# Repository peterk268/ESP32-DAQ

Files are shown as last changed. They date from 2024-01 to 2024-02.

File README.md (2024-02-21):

# V2

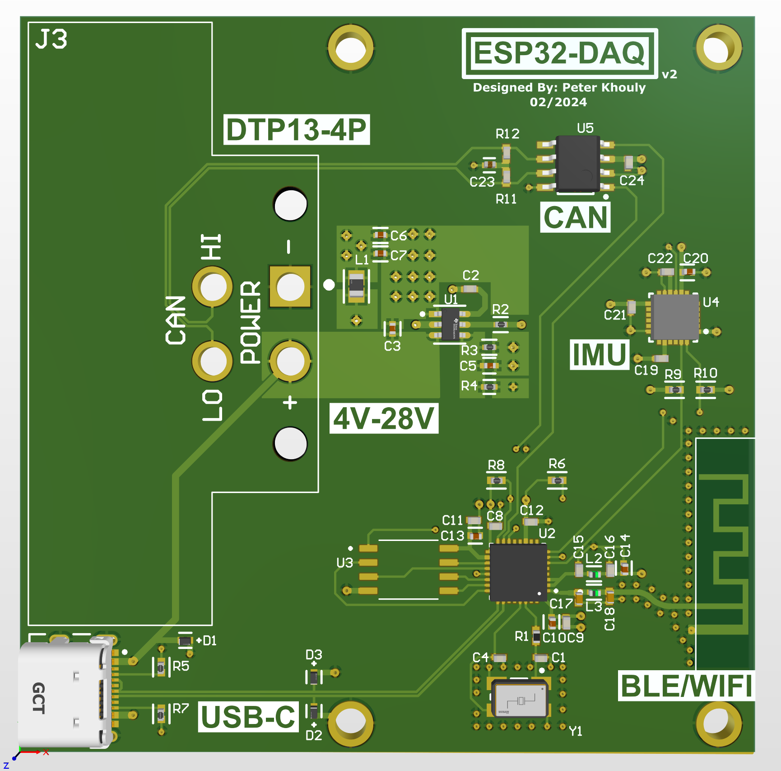
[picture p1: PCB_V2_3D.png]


# V1

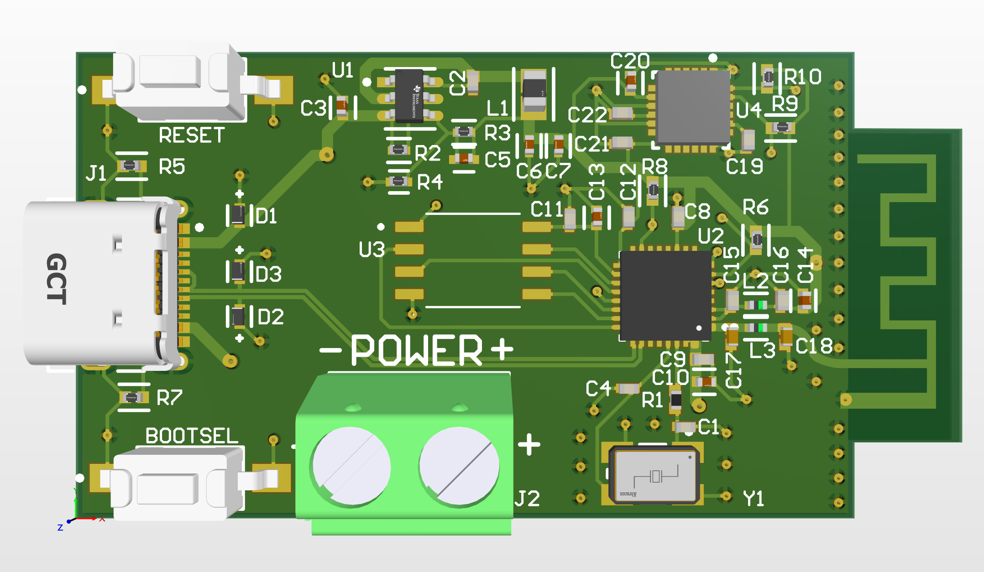
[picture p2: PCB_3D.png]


[Schematic.pdf](https://github.com/peterk268/ESP32-DAQ/blob/main/Schematic.pdf)

[PCB.pdf](https://github.com/peterk268/ESP32-DAQ/blob/main/PCB.pdf)

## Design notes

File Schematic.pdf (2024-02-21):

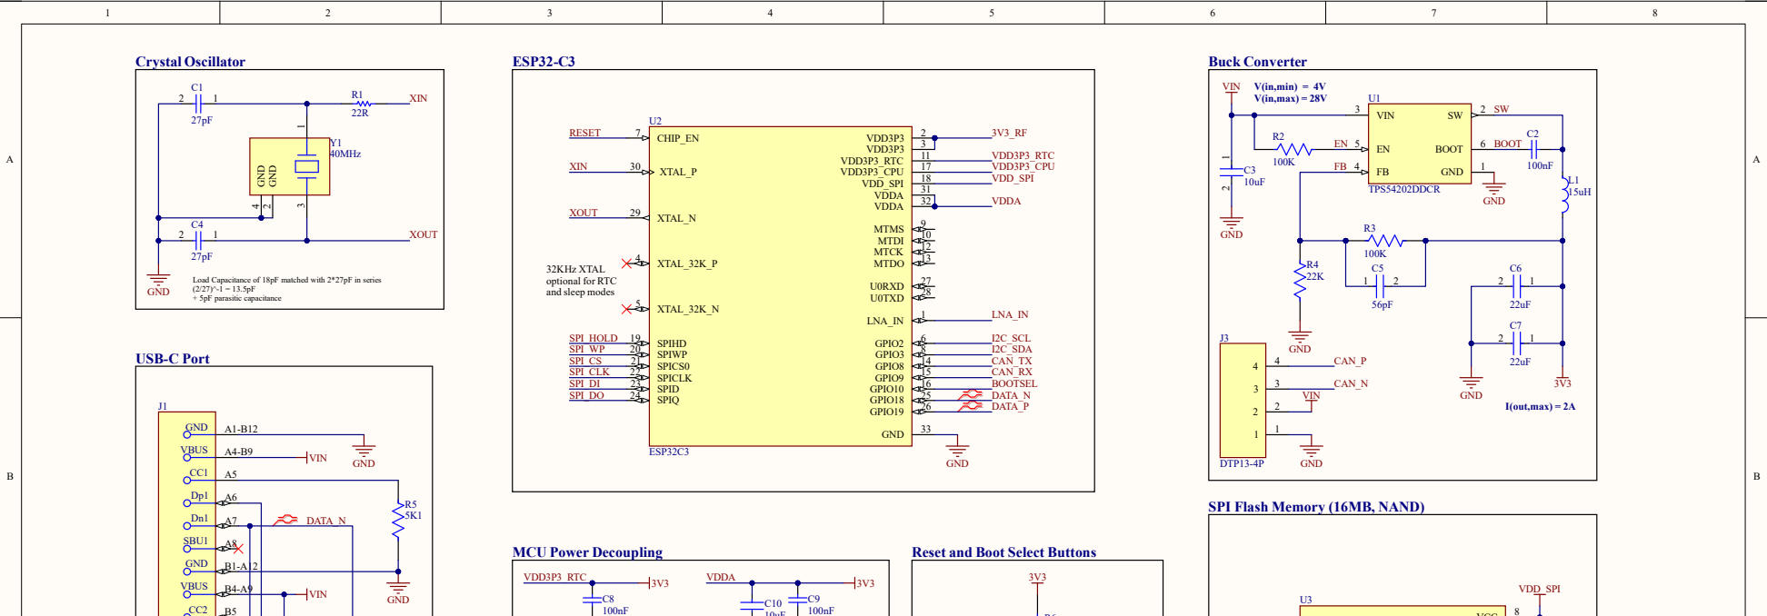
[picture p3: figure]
DATA_N; USB-C Port; VIN; GND; VBUS; SBU1; Crystal Oscillator; XIN; XOUT; (2/27)^-1 = 13.5pF + 5pF parasitic capacitance; Buck Converter 1 2; VIN 3; BOOT; TPS54202DDCR; V(in,max) = 28V; I(out,max) = 2A; CHIP_EN 7; XTAL_P 30; XTAL_N 29; XTAL_32K_P 4; XTAL_32K_N 5; SPIHD 19 SPIWP 20 SPICS0 21 SPICLK 22 SPID 23 SPIQ 24; VDD3P3; VDD3P3_RTC; VDD3P3_CPU; VDD_SPI; VDDA; MTMS; MTDI; MTCK; MTDO; U0RXD; U0TXD; LNA_IN; GPIO2; GPIO3; GPIO8; GPIO9; GPIO10; GPIO18; GPIO19; ESP32C3; DATA_N DATA_P; 32KHz XTAL optional for RTC and sleep modes; VDD3P3_RTC VDD3P3_CPU VDD_SPI; 1 GND; 3 GND; Y1 40MHz; RESET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
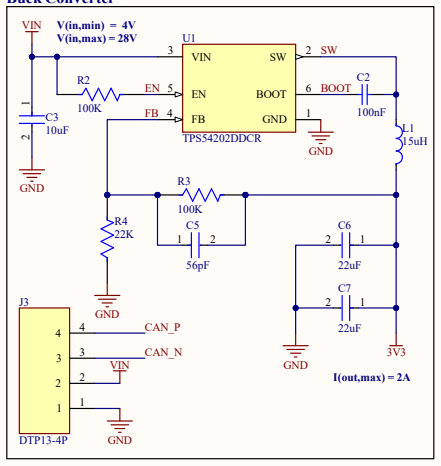
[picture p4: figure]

Load Capacitance of 18pF matched with 2*27pF in series

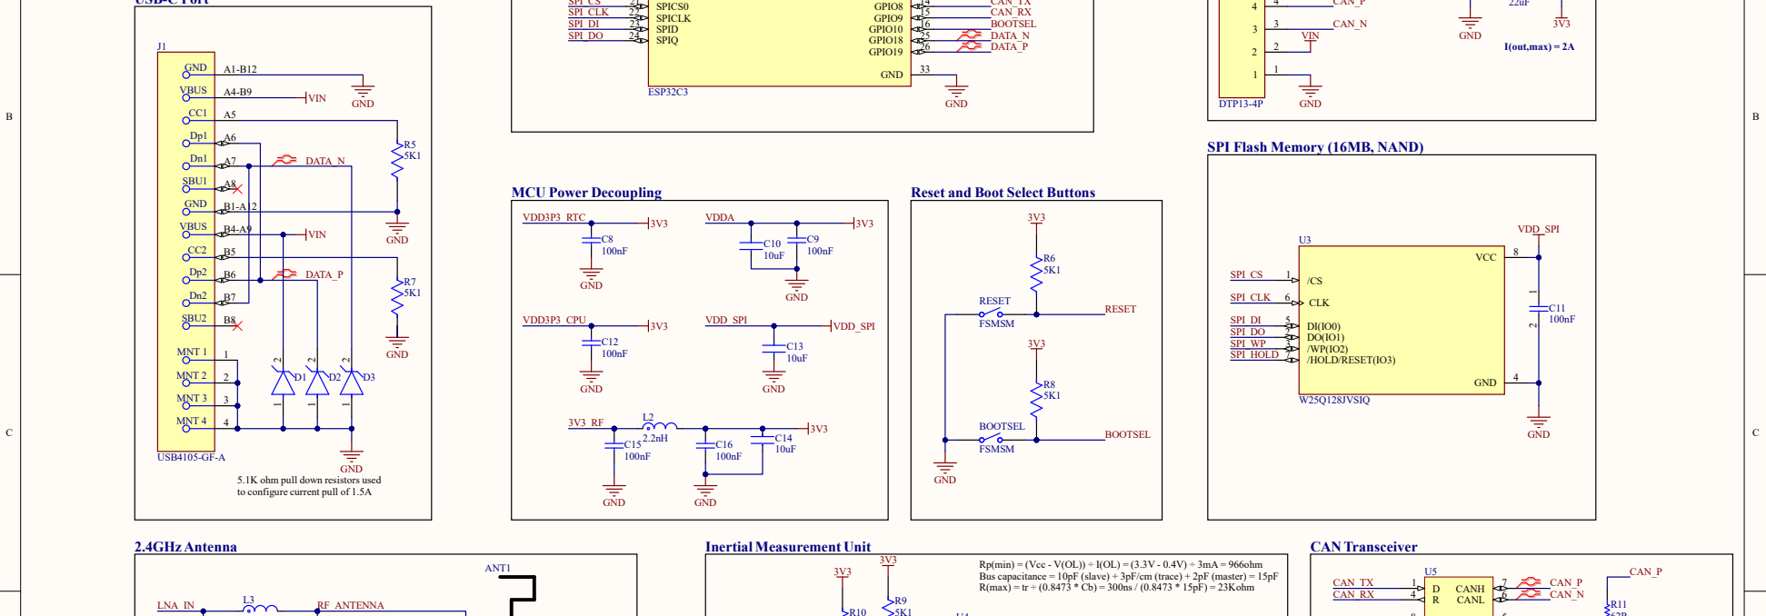
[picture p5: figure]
GND; DATA_P; MNT 1; MNT 2; MNT 3; MNT 4; SBU2; USB4105-GF-A; 5.1K ohm pull down resistors used to configure current pull of 1.5A; GND ¹ ²; VDD3P3_CPU; VDD_SPI; RESET; FSMSM; BOOTSEL; CLK 6; DI(IO0) 5 DO(IO1) 2 /WP(IO2) 3 /HOLD/RESET(IO3) 7; VCC; W25Q128JVSIQ; SPI_CS; SPI_CLK; SPI_DI SPI_DO SPI_WP; SPI_HOLD; 2.4GHz Antenna; ANT1; Inertial Measurement Unit; CANL; CANH; CAN_TX CAN_RX; CAN_P CAN_N; CAN_P; CAN Transceiver
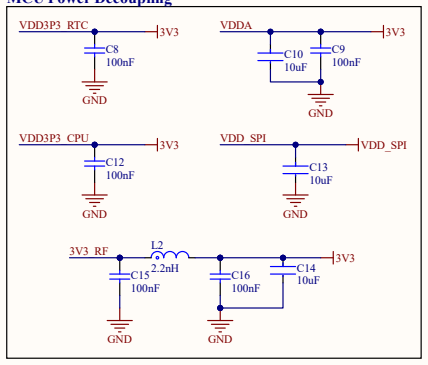
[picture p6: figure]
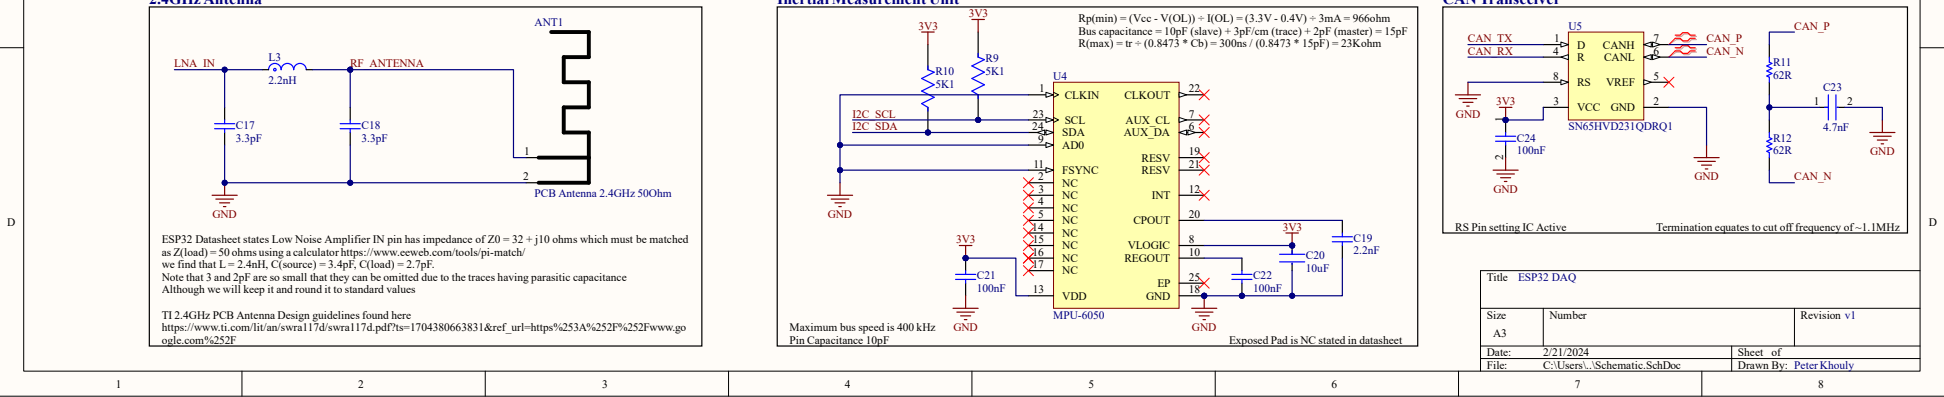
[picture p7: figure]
Title; Size; Number; Revision; Date:; Sheet of; File:; C:\Users\..\Schematic.SchDoc; Drawn By:; https://www.ti.com/lit/an/swra117d/swra117d.pdf?ts=1704380663831&ref_url=https%253A%252F%252Fwww.go ogle.com%252F; LNA_IN; RF_ANTENNA; GND; PCB Antenna 2.4GHz 50Ohm; ESP32 DAQ; Peter Khouly; CLKIN 1; AUX_DA; AUX_CL; VLOGIC; REGOUT; FSYNC 11; INT; VDD 13; RESV; CPOUT; CLKOUT; SCL 23 SDA 24; MPU-6050; Maximum bus speed is 400 kHz Pin Capacitance 10pF; I2C_SCL I2C_SDA; Exposed Pad is NC stated in datasheet; 2 VCC 3; VREF; SN65HVD231QDRQ1; GND ¹ ² C24 100nF; CAN_N

ESP32 Datasheet states Low Noise Amplifier IN pin has impedance of Z0 = 32 + j10 ohms which must be matched as Z(load) = 50 ohms using a calculator https://www.eeweb.com/tools/pi-match/
we find that L = 2.4nH, C(source) = 3.4pF, C(load) = 2.7pF.
Note that 3 and 2pF are so small that they can be omitted due to the traces having parasitic capacitance
Although we will keep it and round it to standard values

TI 2.4GHz PCB Antenna Design guidelines found here

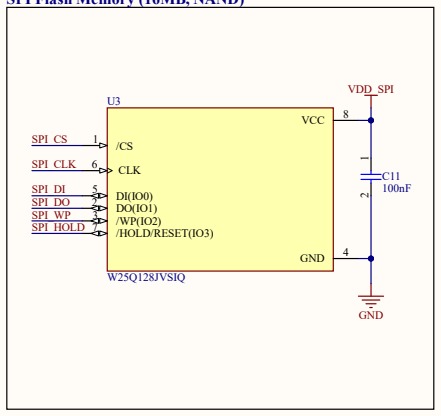
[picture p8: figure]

Rp(min) = (Vcc - V(OL)) ÷ I(OL) = (3.3V - 0.4V) ÷ 3mA = 966ohm Bus capacitance = 10pF (slave) + 3pF/cm (trace) + 2pF (master) = 15pF R(max) = tr ÷ (0.8473 * Cb) = 300ns / (0.8473 * 15pF) = 23Kohm

RS Pin setting IC Active | Termination equates to cut off frequency of ~1.1MHz

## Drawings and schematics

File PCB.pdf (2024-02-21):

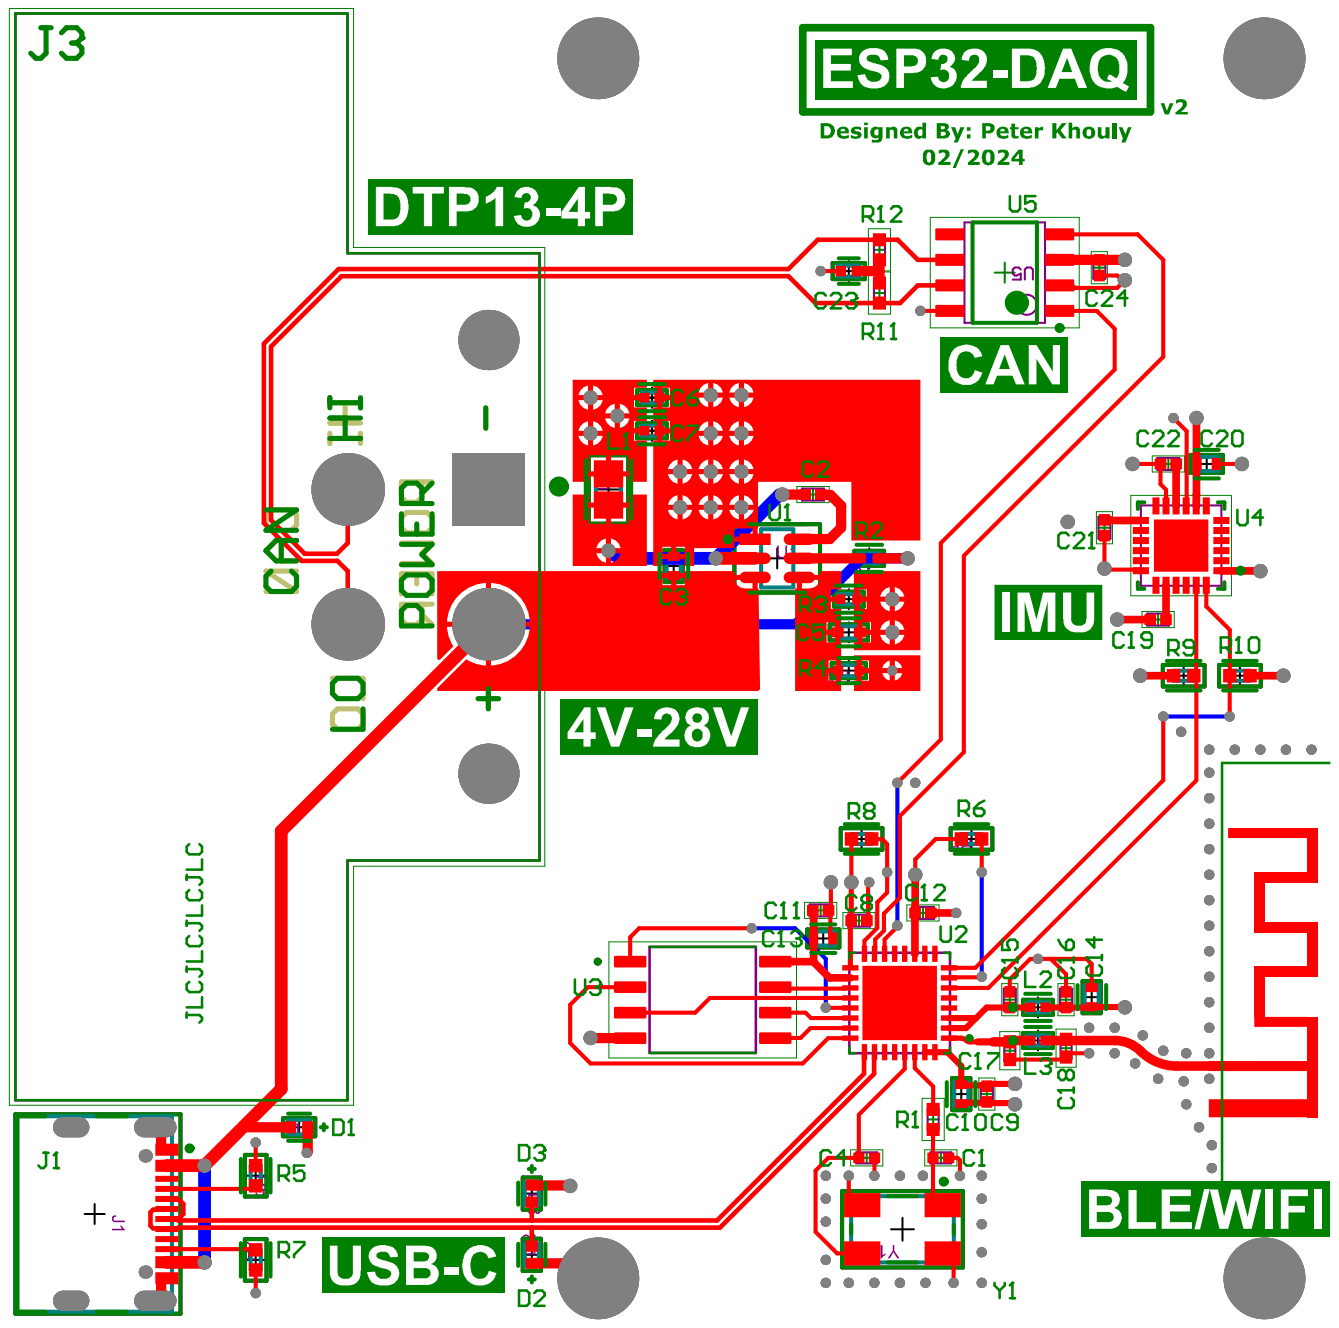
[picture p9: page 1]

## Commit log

2024-01-05 Initial commit, base functionality schematic with 2.4GHz antenna
    [ESP32_DAQ.PrjPcb, PCB.PcbDoc, Schematic.SchDoc]
2024-01-05 2.4GHz Antenna added, PCB Designed 4 layer SIG,GND,GND,SIG. GND cut out under antenna for omnidirectional radiation, all components routed except IMU
    [PCB.PcbDoc, Schematic.SchDoc]
2024-01-05 Fixed some connections
    [PCB.PcbDoc]
2024-01-07 IMU Added
    [PCB.PcbDoc, Schematic.SchDoc]
2024-01-10 Adjusted RF trace width to 18.7mils for 50 ohm, changed stack up to SIG GND PWR SIG
    [PCB.PcbDoc]
2024-01-17 Cut out copper under antenna, gerber generated
    [ESP32_DAQ.PrjPcb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]
2024-01-26 Created PLUS branch
    [PCB.PcbDoc, Schematic.SchDoc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]
2024-02-17 larger board with better SI, SIG GND PWR SIG, better regulator routing, and deustch connector
    [ESP32_DAQ.PrjPcb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]
2024-02-21 Added CAN Transceiver, removed buttons, generated new gerber
    [ESP32_DAQ.PrjPcb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]
2024-02-21 v2 pdfs
    [pcb.gbl, pcb.gbo, pcb.gbs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]
2024-03-17 Changed vias to direct connect, fixed IMU power
    [ESP32_DAQ.PrjPcb]
